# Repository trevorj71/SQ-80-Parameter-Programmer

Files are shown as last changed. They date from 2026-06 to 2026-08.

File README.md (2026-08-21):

# PG-80 Crosswave Parameter Programmer for Ensoniq SQ-80 and Ensoniq ESQ1

This repo contains open source hardware and software for the Ensoniq SQ-80 and ESQ-1 hybrid synthesizers, which I have named the "PG-80". It allows you to program up to 63 parameters in your synthesis engine using the 32 knobs on the front panel. It also supports hidden waves if your synth is equipped with an OS that supports them on the front panel. It also features a MIDI merge feature so you can run an input from your MIDI interface through the programmer to the synth, inserting the programmer in-line so it doesn't add unnecessarily to your workflow or MIDI rats nest.

I'm still tweaking the firmware to improve the knob layout and I have a new housing version in progress to accomodate a larger OLED display, but the current design is debugged and functional.

A BOM will be forthcoming when I have a few minutes to add it.

# Housing

My vision for this unit was always been a sidecar that can sit next to the synth on a stand designed for a 76 key workstation and looks like an extension of the synth to the extent possible.  Likely, you could design a smaller housing for desktop, as mine is not necessarily designed
to minimize its footprint or print time. 

The 3D models for the prototype are will be published here in both Fusion 360 and STL formats.

## Prototype Version (Adafruit 326 and PCB Mounted MIDI Connections)

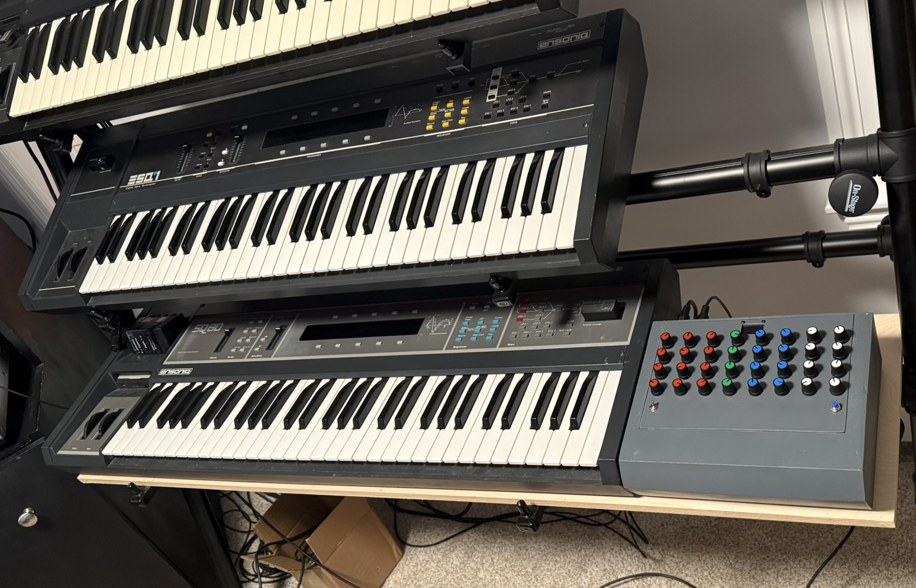
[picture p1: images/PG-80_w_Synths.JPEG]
PG-80 Programmer prototype with Ensoniq SQ-80 and Ensonig ESQ-1


For my first build, I used PCB mounted MIDI connectors and a PCB that was optimized for production and shipping cost. This left me with limited space between the knob array and the back panel of the unit for an OLED, so I used an Adafruit 326 0.91mm display.  This was fine for prototyping but in practice in the studio it is really hard to read.  Otherwise the knob layout feels good and the overall geometry of the print meets the vision. 

I did have some slippage in my printer late in this job (which took 5 days) so there is a bit of a bondo job on this, but it works for a prototype.

## In Progress Updgraded Version (Adafruit ... and Panel Mounted MIDI Connecitons)

Build two will switch to a 2.42 inch Adafruit 2719 and panel mounted MIDI connections. Design for that enclosure is under way.

# Glitch Mode (Hidden Waveform) and Shift Switch

This momentary pushbutton switch, SW2, has two functions. 

A quick tap of this swtich enables glitch mode. This allows knobs 1-3 (oscillator waveforms) to transmit all 255 available parameters to the synth. If you have an OS for your synth that supports hidden waveforms, you will be able to scroll through all 255 paramteters. This only works with the modified OS versions that support hidden waves.

Pressing and holding this switch while also turning a knob makes it function as a shift key, letting you change the MIDI channel on your device or modify up to 63 parameters in your synthesis workflow. Failing to turn a knob while the switch is depressed reverts the programmer to Glitch Mode / Standard Mode.

# Arch Mode (SQ-80 / ESQ-1) Toggle

A panel mounted toggle switch, SW1, facilitates switching between the 32 wave ESQ-1 table and the 75 wave SQ-80 table. In standard mode, this aligns the values sent by the oscillator waveform knobs within the desired range for your model synth. In Glitch Mode, this is more a matter of the mask used for the OLED on parameters 33-75, since all 255 parameters can be transmitted to the synth.

# Potentiometer Layout

Currently, the programmer has been laid out with 32 Potentiometers. You can access up to 63 parameters plus MIDI channel by pressing and holding the Hidden Waveforms button like a shift key.  

The knob layout as of version 1.5 is as follows:

### GLITCH BUTTON IN THE UP POSITION - NOT PRESSED

| Oscillator 1 | Oscillator 2 | Oscillator 3 | DCA-Filter | MOD 1 | MOD 2 | ENV 1-3 | ENV 2-4 
| :---: | :---: | :---: | :---: | :---: | :---: | :---: | :---: |
| WAVEFORM | WAVEFORM | WAVEFORM | DCA1 VOL | LFO1 WAVE | LFO2 FREQ | ENV1 ATK | ENV2 ATK 
| OSC1 FINE | OSC2 FINE | OSC3 FINE | DCA2 VOL | LFO1 FREQ | LFO3 WAVE | ENV1 DEC | ENV2 DEC 
| OSC1 COAR | OSC2 COAR | OSC3 COAR | DCA3 VOL | LFO1 DELY | LFO3 FREQ | ENV1 REL | ENV2 REL
| OSC1 OCT | OSC2 OCT | OSC3 OCT | ENV4 VOL | LFO2 WAVE | LFO3 DELY | ENV1 SUS | ENV2 SUS 

### GLITCH BUTTON HELD DOWN WHILE TURNING

| Oscillator 1 | Oscillator 2 | Oscillator 3 | DCA-Filter | MOD 1 | MOD 2 | ENV 1-3 | ENV 2-4 
| :---: | :---: | :---: | :---: | :---: | :---: | :---: | :---: |
| MOD1 SRC | MOD1 SRC | MOD1 SRC | FILT CUT | LFO1 L1 | LFO2 LS | ENV3 ATK | ENV4 ATK 
| MOD1 LEV | MOD1 LEV | MOD1 LEV | FILT RES | LFO1 L2 | LFO3 L1` | ENV3 DEC | ENV4 DEC 
| MOD2 SRC | MOD2 SRC | MOD2 SRC | FILT MOD3 | LFO2 DELY | LFO3 L2 | ENV3 REL | ENV4 REL
| MOD2 LEV | MOD2 LEV | MOD2 LEV | VOICE PAN | LFO2 L1 | MIDI CHAN | ENV3 SUS | ENV4 SUS

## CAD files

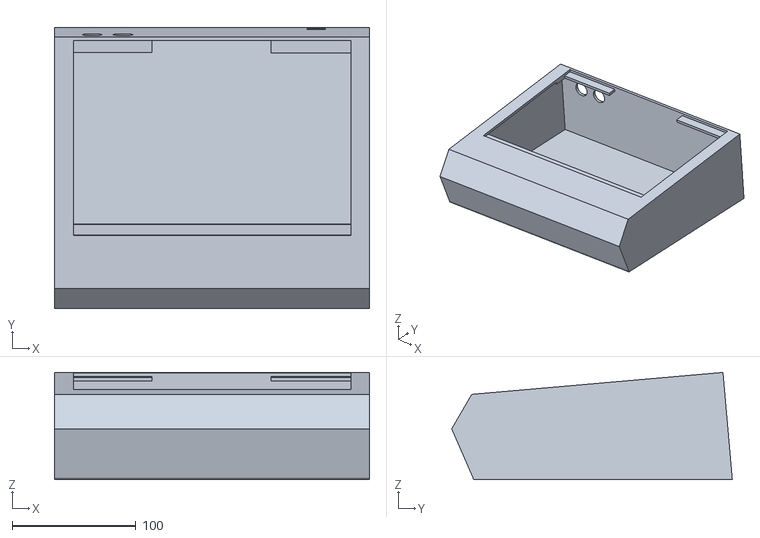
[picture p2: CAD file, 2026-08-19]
PG-80_Enclosure/V1-091 Display/Sliced Files/SQ80_Programmer_Housing_1_1.stl
255.0 x 227.2 x 86.7

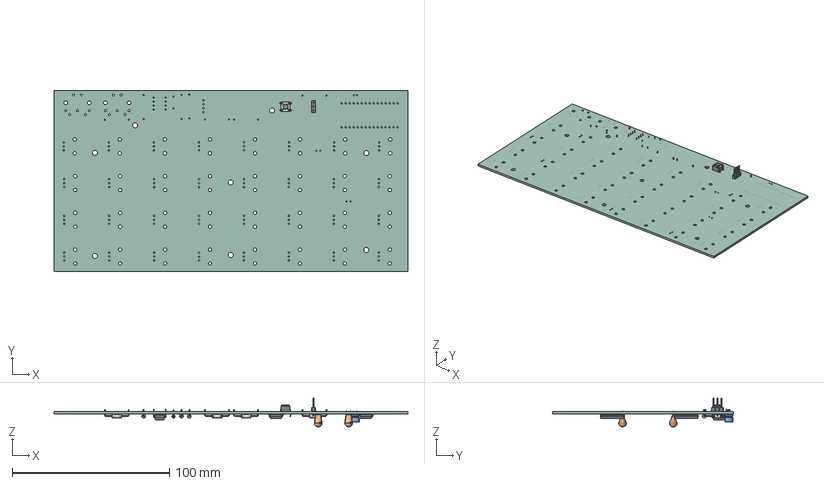
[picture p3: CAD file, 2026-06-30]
SQ80_Programmer_KiCad/PG-80.step
225.0 x 115.0 x 18.3 mm
SW_PUSH_6mm
PinHeader_1x03_P254mm_Vertical
DIP-8_W7.62mm
R_Axial_DIN0207_L63mm_D25mm_P1524mm_Horizontal x 7
SOIC-24W_7.5x15.4mm_P1.27mm x 2
CP_Radial_Tantal_D50mm_P250mm x 2
D_DO-35_SOD27_P7.62mm_Horizontal
CP_Radial_D50mm_P200mm
SQ80_Hardware_Programmer_PCB

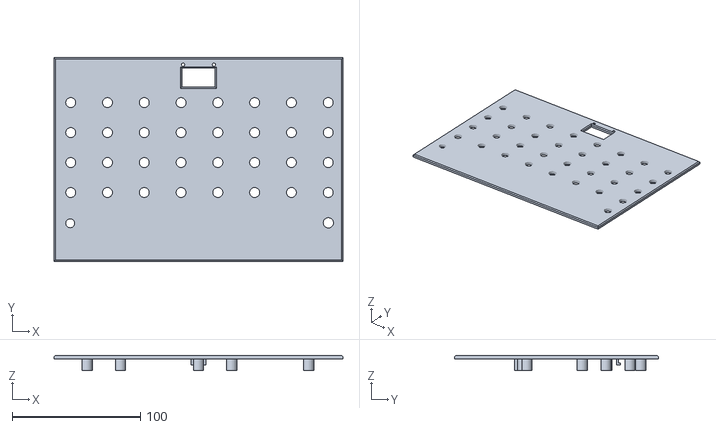
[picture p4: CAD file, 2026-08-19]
PG-80_Enclosure/V1-091 Display/Sliced Files/SQ-80_Lid4.stl
225.0 x 158.6 x 12.0

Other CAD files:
PG-80_Enclosure/V1-091 Display/Fusion360/SQ-80-2.f3d
PG-80_Enclosure/V1-091 Display/Fusion360/SQ-80_Lid2.f3d

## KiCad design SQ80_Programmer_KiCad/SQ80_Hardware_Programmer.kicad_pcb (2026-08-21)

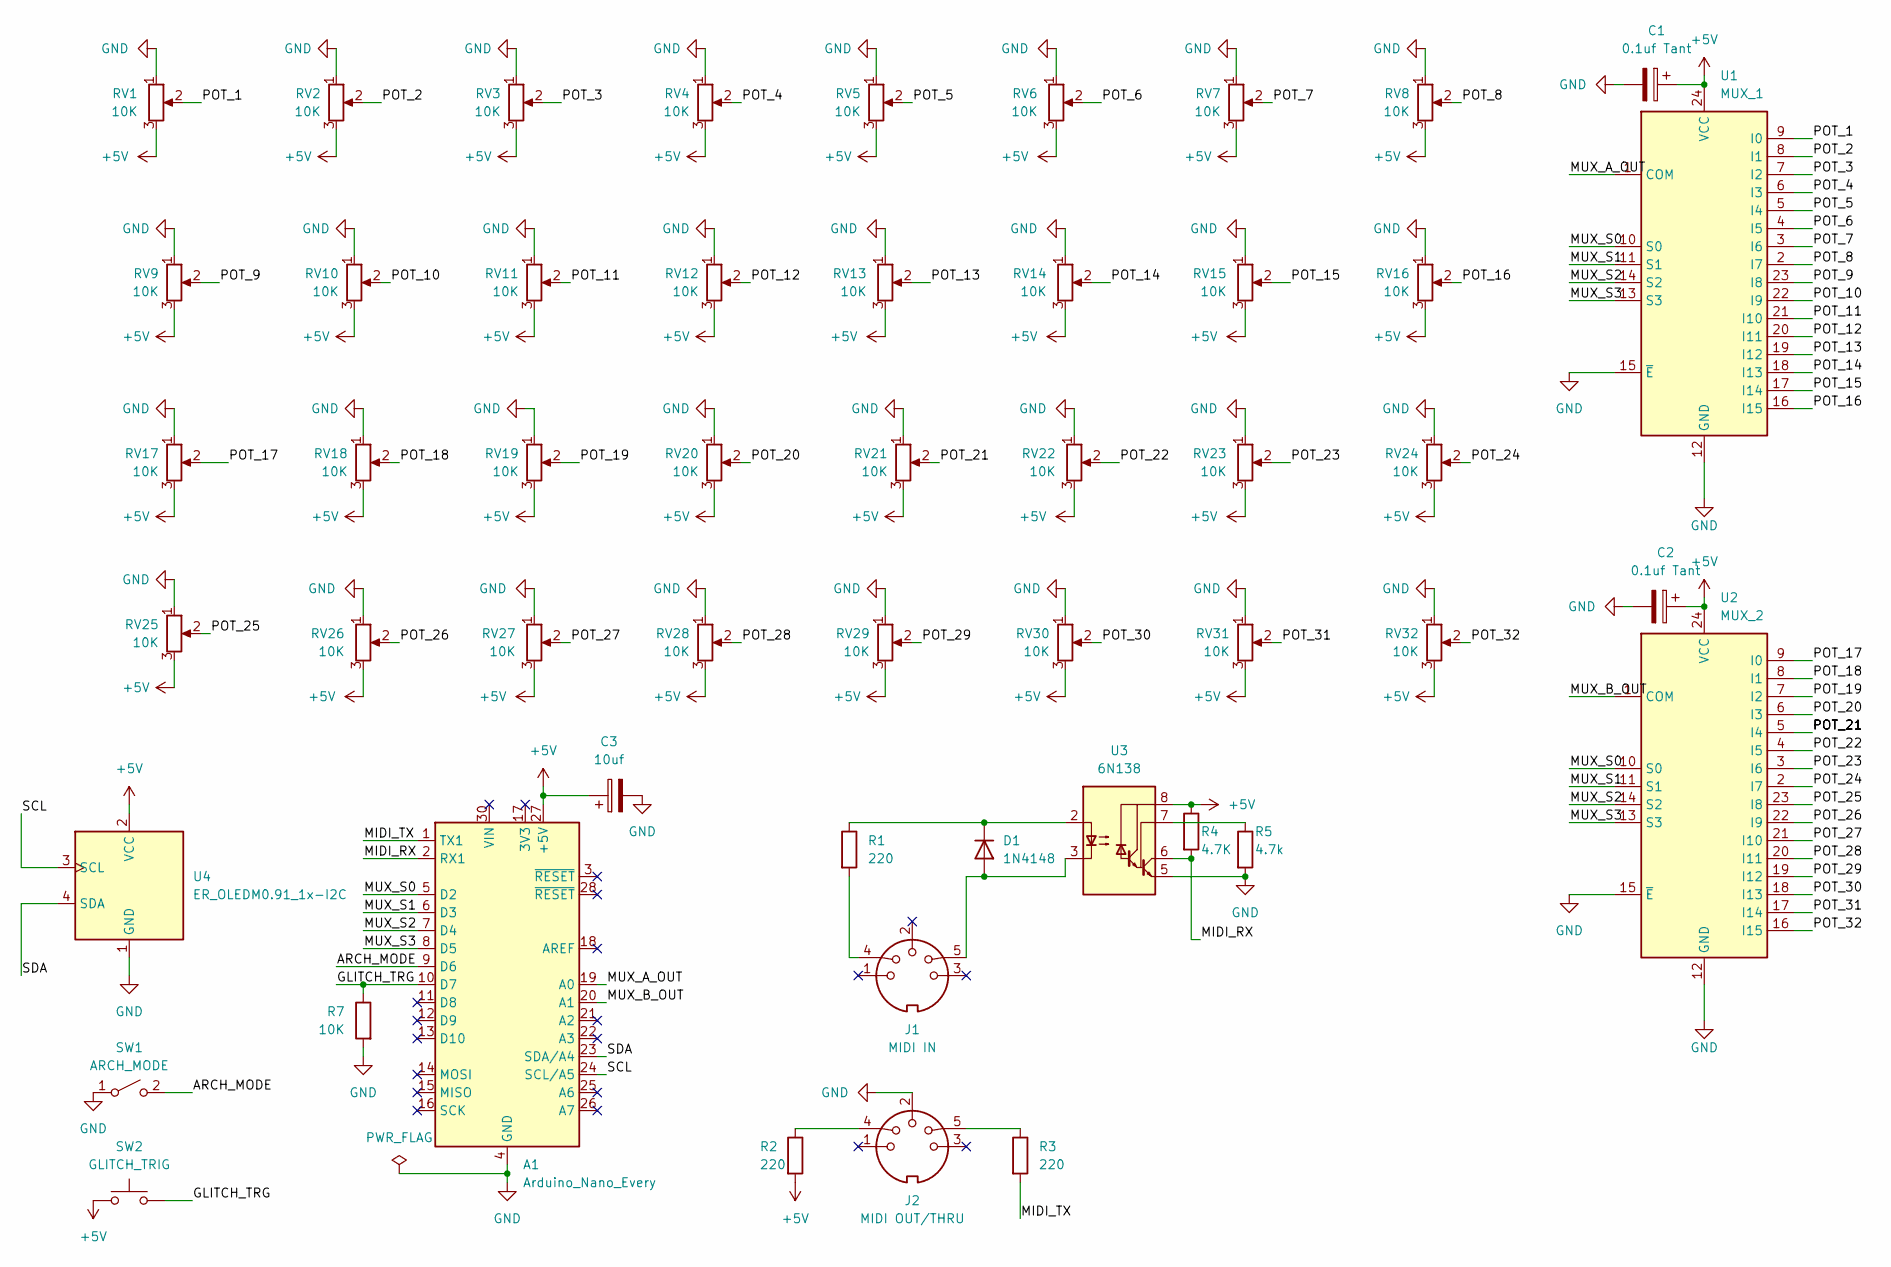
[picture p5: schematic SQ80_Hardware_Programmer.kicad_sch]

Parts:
A1: Arduino_Nano_Every; Arduino_Nano
C1, C2: 0.1uf Tant; CP_Radial_Tantal_D5.0mm_P2.50mm
C3: 10uf; CP_Radial_D5.0mm_P2.00mm
D1: 1N4148; D_DO-35_SOD27_P7.62mm_Horizontal
J1: MIDI IN; CONN5_SDS-50J_CUD
J2: MIDI OUT/THRU; CONN5_SDS-50J_CUD
R1, R2, R3: 220; R_Axial_DIN0207_L6.3mm_D2.5mm_P15.24mm_Horizontal
R4: 4.7K; R_Axial_DIN0207_L6.3mm_D2.5mm_P15.24mm_Horizontal
R5: 4.7k; R_Axial_DIN0207_L6.3mm_D2.5mm_P15.24mm_Horizontal
R7: 10K; R_Axial_DIN0207_L6.3mm_D2.5mm_P15.24mm_Horizontal
RV1, RV2, RV3, RV4, RV5, RV6, RV7, RV8, RV9, RV10, RV11, RV12, RV13, RV14, RV15, RV16, RV17, RV18, RV19, RV20, RV21, RV22, RV23, RV24, RV25, RV26, RV27, RV28, RV29, RV30, RV31, RV32: 10K; Potentiometer_Bourns_PTV09A-1_Single_Vertical
SW1: ARCH_MODE; PinHeader_1x03_P2.54mm_Vertical
SW2: GLITCH_TRIG; SW_PUSH_6mm
U1: MUX_1; SOIC-24W_7.5x15.4mm_P1.27mm
U2: MUX_2; SOIC-24W_7.5x15.4mm_P1.27mm
U3: 6N138; DIP-8_W7.62mm
U4: ER_OLEDM0.91_1x-I2C

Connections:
+5V: A1.27 (+5V), C1.1, C2.1, C3.1, R2.2, R4.1, RV1.3, RV2.3, RV3.3, RV4.3, RV5.3, RV6.3, RV7.3, RV8.3, RV9.3, RV10.3, RV11.3, RV12.3, RV13.3, RV14.3, RV15.3, RV16.3, RV17.3, RV18.3, RV19.3, RV20.3, RV21.3, RV22.3, RV23.3, RV24.3, RV25.3, RV26.3, RV27.3, RV28.3, RV29.3, RV30.3, RV31.3, RV32.3, SW2.1, U1.24 (VCC), U2.24 (VCC), U3.8 (VCC), U4.2 (VCC)
/ARCH_MODE: A1.9 (D6), SW1.2 (B)
/GLITCH_TRG: A1.10 (D7), R7.1, SW2.2
/MIDI_RX: A1.2 (RX1), R4.2, U3.6 (VO2)
/MIDI_TX: A1.1 (TX1), R3.2
/MUX_A_OUT: A1.19 (A0), U1.1 (COM)
/MUX_B_OUT: A1.20 (A1), U2.1 (COM)
/MUX_S0: A1.5 (D2), U1.10 (S0), U2.10 (S0)
/MUX_S1: A1.6 (D3), U1.11 (S1), U2.11 (S1)
/MUX_S2: A1.7 (D4), U1.14 (S2), U2.14 (S2)
/MUX_S3: A1.8 (D5), U1.13 (S3), U2.13 (S3)
/POT_1: RV1.2, U1.9 (I0)
/POT_2: RV2.2, U1.8 (I1)
/POT_3: RV3.2, U1.7 (I2)
/POT_4: RV4.2, U1.6 (I3)
/POT_5: RV5.2, U1.5 (I4)
/POT_6: RV6.2, U1.4 (I5)
/POT_7: RV7.2, U1.3 (I6)
/POT_8: RV8.2, U1.2 (I7)
/POT_9: RV9.2, U1.23 (I8)
/POT_10: RV10.2, U1.22 (I9)
/POT_11: RV11.2, U1.21 (I10)
/POT_12: RV12.2, U1.20 (I11)
/POT_13: RV13.2, U1.19 (I12)
/POT_14: RV14.2, U1.18 (I13)
/POT_15: RV15.2, U1.17 (I14)
/POT_16: RV16.2, U1.16 (I15)
/POT_17: RV17.2, U2.9 (I0)
/POT_18: RV18.2, U2.8 (I1)
/POT_19: RV19.2, U2.7 (I2)
/POT_20: RV20.2, U2.6 (I3)
/POT_21: RV21.2, U2.5 (I4)
/POT_22: RV22.2, U2.4 (I5)
/POT_23: RV23.2, U2.3 (I6)
/POT_24: RV24.2, U2.2 (I7)
/POT_25: RV25.2, U2.23 (I8)
/POT_26: RV26.2, U2.22 (I9)
/POT_27: RV27.2, U2.21 (I10)
/POT_28: RV28.2, U2.20 (I11)
/POT_29: RV29.2, U2.19 (I12)
/POT_30: RV30.2, U2.18 (I13)
/POT_31: RV31.2, U2.17 (I14)
/POT_32: RV32.2, U2.16 (I15)
/SCL: A1.24 (SCL/A5), U4.3 (SCL)
/SDA: A1.23 (SDA/A4), U4.4 (SDA)
GND: A1.4 (GND), A1.29 (GND), C1.2, C2.2, C3.2, J2.2, R5.2, R7.2, RV1.1, RV2.1, RV3.1, RV4.1, RV5.1, RV6.1, RV7.1, RV8.1, RV9.1, RV10.1, RV11.1, RV12.1, RV13.1, RV14.1, RV15.1, RV16.1, RV17.1, RV18.1, RV19.1, RV20.1, RV21.1, RV22.1, RV23.1, RV24.1, RV25.1, RV26.1, RV27.1, RV28.1, RV29.1, RV30.1, RV31.1, RV32.1, SW1.1 (A), U1.12 (GND), U1.15 (~E), U2.12 (GND), U2.15 (~E), U3.5 (GND), U4.1 (GND)
unnamed: D1.2 (A), J1.5, U3.3 (C2)
unnamed: D1.1 (K), R1.1, U3.2 (C1)
unnamed: J1.4, R1.2
unnamed: J2.4, R2.1
unnamed: J2.5, R3.1
unnamed: R5.1, U3.7 (VO1)

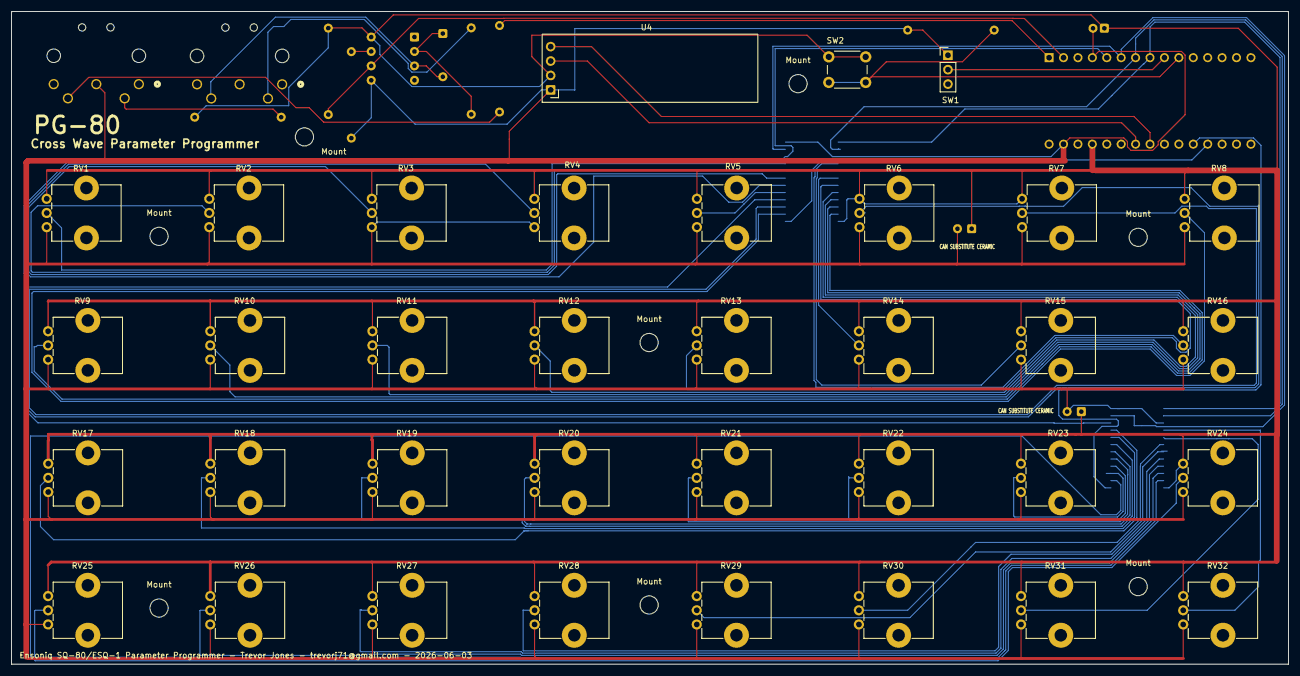
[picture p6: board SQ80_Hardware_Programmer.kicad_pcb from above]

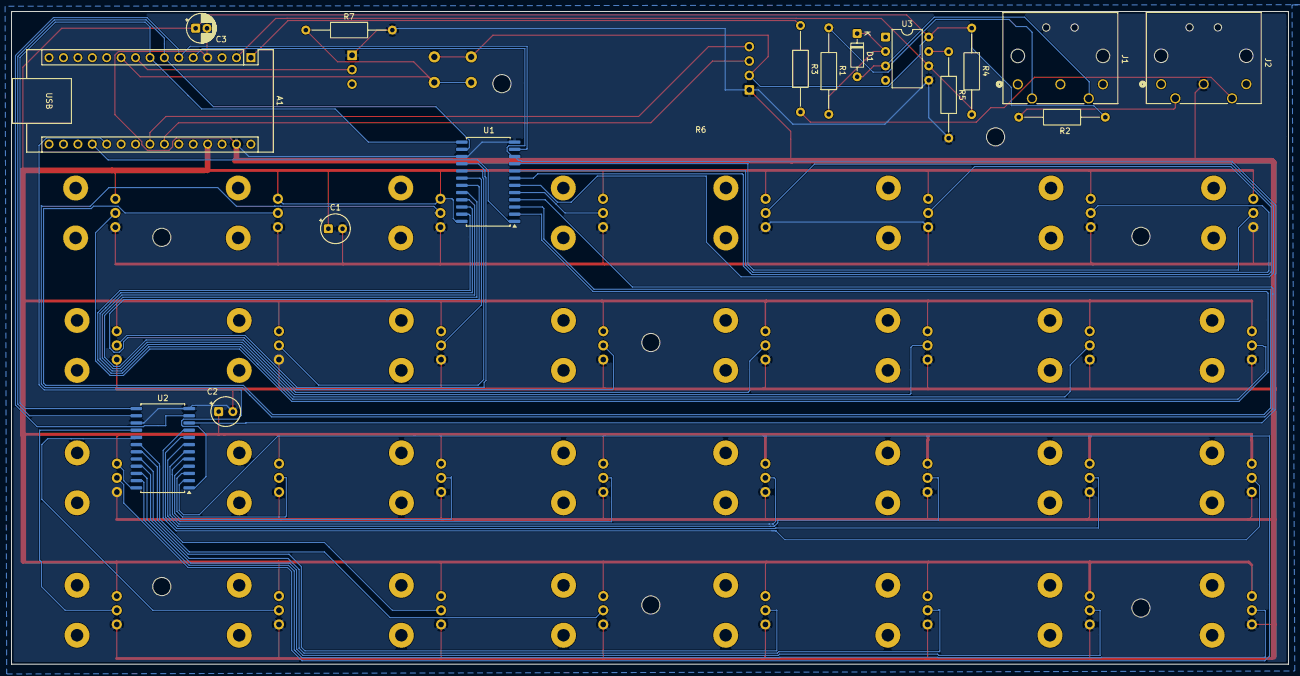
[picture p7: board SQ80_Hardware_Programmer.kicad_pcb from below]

Board: 2 copper layers, 225.0 x 115.0 mm, 59 parts (16 on the bottom side), 52 nets.

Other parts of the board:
Mount: MountingHole_3.2mm_M3
Mount#2, Mount#3, Mount#4, Mount#5, Mount#6, Mount#7, Mount#8: MountingHole_3.2mm_M3

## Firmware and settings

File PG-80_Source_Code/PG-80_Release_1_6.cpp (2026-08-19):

C++

#include <Wire.h>
#include <Adafruit_GFX.h>
#include <Adafruit_SSD1306.h>

// --- OLED DISPLAY CONFIGURATION ---
#define SCREEN_WIDTH 128
#define SCREEN_HEIGHT 64
Adafruit_SSD1306 display(SCREEN_WIDTH, SCREEN_HEIGHT, &Wire, -1);

// --- HARDWARE PIN DEFINITIONS ---
const int s0 = 2;
const int s1 = 3;
const int s2 = 4;
const int s3 = 5;

const int muxA = A0; // Channels 0-15 (Physical Pots 1-16)
const int muxB = A1; // Channels 0-15 (Physical Pots 17-32)

const int modelSwitchPin = 6;  
const int glitchButtonPin = 7; // Multi-gesture shift layer / glitch input button

// --- SYSTEM STATE VARIABLES ---
int lastPotState[32] = {0};
const int hysteresis = 8;         
bool isSQ80 = true;               
bool glitchMode = false;          // Starts up at "Hidden Waves: OFF"
bool lastGlitchButtonState = LOW;  // matches INPUT_PULLDOWN idle state

// --- GLOBAL MIDI SETTINGS ---
int midiChannel = 1;              

// --- ERA-ACCURATE FACTORY WAVEFORM LOOKUP TABLES ---
const char* const esq1Waves[32] = {
  "SAW", "SQUARE", "PULSE", "SINE", "NOISE", "REED", "ORGAN", "VOICE",
  "CHORD", "SYNTH", "BASS", "PIANO", "EL PNO", "VOX 1", "VOX 2", "BREATH",
  "DRUM 1", "DRUM 2", "DRUM 3", "KICK", "SNARE", "TOM", "HI-HAT", "PERC 1",
  "SYN 2", "SYN 3", "MELLON", "OCTAVE", "FIFTH", "PIRATE", "GHOST", "HEAVEN"
};
const char* const sq80ExtraWaves[43] = {
  "GLINT 1", "GLINT 2", "GLINT 3", "GLINT 4", "GLINT 5", "GLINT 6", "GRIT 1", "GRIT 2", 
  "GRIT 3", "WRONG", "SNARE", "KICK", "TOM", "HI-HAT", "RIM", "BREATH", 
  "VOICE 2", "STEAM", "METAL", "CHIME", "BOWED", "STRUCK", "PLUCK", "PLINK", 
  "CHIFF", "THUMP", "CLICK", "LOG", "XLYO", "MALLET", "ORGAN 2", "NEIGH", 
  "ROBOT", "SQUAWK", "ALARM", "REVERSE", "LOOP 1", "LOOP 2", "LOOP 3", "LOOP 4", 
  "LOOP 5", "LOOP 6", "MAC"
};
const char* const lfoWaves[5] = {
  "TRIANGLE", "SAWTOOTH", "SQUARE", "RANDOM", "NOISE"
};

// --- PARAMETER LOOKUP TABLE: COLUMN-FIRST LAYOUT ---
// Physical layout: 8 columns x 4 rows, read left-to-right top-to-bottom.
// Each column groups a parameter family so pots in the same column are
// visually consistent with the SQ-80's front panel button groupings.
const int sq80Parameters[32] = {
  // Row 1 (Pots 1-8):   one pot per column, top knob of each group
  3,  7,  11, 12, 17, 24, 43, 50,
  // Pots 1-8: OSC1 Wave | OSC2 Wave | OSC3 Wave | DCA1 Vol | LFO1 Wave | LFO2 Freq | ENV1 Atk | ENV2 Atk

  // Row 2 (Pots 9-16):  second knob of each group
  1,  5,  9,  13, 15, 35, 44, 51,
  // Pots 9-16: OSC1 Semi | OSC2 Semi | OSC3 Semi | DCA2 Vol | LFO1 Freq | LFO3 Wave | ENV1 Dec | ENV2 Dec

  // Row 3 (Pots 17-24): third knob of each group
  2,  6,  10, 14, 16, 33, 46, 53,
  // Pots 17-24: OSC1 Fine | OSC2 Fine | OSC3 Fine | DCA3 Vol | LFO1 Dly | LFO3 Freq | ENV1 Rel | ENV2 Rel

  // Row 4 (Pots 25-32): fourth/bottom knob of each group
  0,  4,  8,  23, 26, 32, 48, 55
  // Pots 25-32: OSC1 Oct | OSC2 Oct | OSC3 Oct | Patch Vol | LFO2 Wave | LFO3 Dly | ENV1 Sus | ENV2 Sus
};

// Track whether Pot 32 was adjusted while shift was held down
bool pot32AdjustedDuringShift = false;

// Track what's currently on screen so other events (e.g. model switch) can redraw it
int lastDisplayedParamID = -1;
int lastDisplayedValue = 0;

// Reads a pot's raw ADC value with rotation direction inverted, so that
// clockwise rotation increases the value (matching typical studio gear),
// instead of the hardware's native counter-clockwise-to-increase wiring.
int readPot(int analogPin) {
  return 1023 - analogRead(analogPin);
}

// --- ENSONIQ HARDWARE MIDI PARAMETER TRANSLATOR ---
// Returns -1 for parameters whose NRPN address is not yet confirmed from the
// manual. The send path skips transmission for -1 to prevent corrupting the
// patch with a garbage address. Verify and fill these in after bench testing.
int translateToEnsoniqParam(int internalID) {
  switch(internalID) {
    // OSC 1 (NRPN block 64-71)
    case 0:  return 64; // OSC 1 OCTAVE
    case 1:  return 65; // OSC 1 SEMI
    case 2:  return 66; // OSC 1 FINE
    case 3:  return 67; // OSC 1 WAVE
    case 70: return 68; // OSC 1 MOD 1 SOURCE
    case 71: return 69; // OSC 1 MOD 1 LEVEL
    case 72: return 70; // OSC 1 MOD 2 SOURCE
    case 73: return 71; // OSC 1 MOD 2 LEVEL

    // OSC 2 (NRPN block 72-79)
    case 4:  return 72; // OSC 2 OCTAVE
    case 5:  return 73; // OSC 2 SEMI
    case 6:  return 74; // OSC 2 FINE
    case 7:  return 75; // OSC 2 WAVE
    case 74: return 76; // OSC 2 MOD 1 SOURCE
    case 75: return 77; // OSC 2 MOD 1 LEVEL
    case 76: return 78; // OSC 2 MOD 2 SOURCE
    case 77: return 79; // OSC 2 MOD 2 LEVEL

    // OSC 3 (NRPN block 80-87)
    case 8:  return 80; // OSC 3 OCTAVE
    case 9:  return 81; // OSC 3 SEMI
    case 10: return 82; // OSC 3 FINE
    case 11: return 83; // OSC 3 WAVE
    case 78: return 84; // OSC 3 MOD 1 SOURCE
    case 79: return 85; // OSC 3 MOD 1 LEVEL
    case 80: return 86; // OSC 3 MOD 2 SOURCE
    case 81: return 87; // OSC 3 MOD 2 LEVEL

    // DCA / VCF
    case 12: return 88; // DCA 1 LEVEL
    case 13: return 94; // DCA 2 LEVEL
    case 14: return 100;// DCA 3 LEVEL
    case 18: return 110;// FILTER CUTOFF
    case 19: return 111;// FILTER RESONANCE
    case 82: return 112;// FILTER MODULATION AMOUNT 3

    // LFO 1 (NRPN block 40-47)
    case 15: return 40; // LFO 1 FREQ
    case 16: return 45; // LFO 1 DELAY
    case 17: return 43; // LFO 1 WAVE
    case 83: return 44; // LFO 1 L1
    case 84: return 46; // LFO 1 L2

    // LFO 2 (NRPN block 48-55)
    case 24: return 48; // LFO 2 FREQ
    case 25: return 53; // LFO 2 DELAY
    case 26: return 51; // LFO 2 WAVE
    case 85: return 52; // LFO 2 L1
    case 86: return 54; // LFO 2 L2

    // LFO 3 (NRPN block 56-63)
    case 33: return 56; // LFO 3 FREQ
    case 32: return 61; // LFO 3 DELAY
    case 35: return 59; // LFO 3 WAVE
    case 87: return 60; // LFO 3 L1
    case 88: return 62; // LFO 3 L2

    // Misc
    case 23: return 30; // PATCH VOLUME (DCA 4 VOL)
    case 42: return 107;// PAN POSITION

    // ENV 1 (NRPN block 0-9)
    case 43: return 5;  // ENV 1 T1 (Attack)
    case 44: return 6;  // ENV 1 T2 (Decay)
    case 46: return 8;  // ENV 1 T4 (Release)
    case 48: return 2;  // ENV 1 L3 (Sustain)

    // ENV 2 (NRPN block 10-19)
    case 50: return 15; // ENV 2 T1 (Attack)
    case 51: return 16; // ENV 2 T2 (Decay)
    case 53: return 18; // ENV 2 T4 (Release)
    case 55: return 12; // ENV 2 L3 (Sustain)

    // ENV 3 (NRPN block 20-29)
    case 56: return 25; // ENV 3 T1 (Attack)
    case 57: return 26; // ENV 3 T2 (Decay)
    case 59: return 28; // ENV 3 T4 (Release)
    case 62: return 22; // ENV 3 L3 (Sustain)

    // ENV 4 (NRPN block 30-39)
    case 64: return 35; // ENV 4 T1 (Attack)
    case 65: return 36; // ENV 4 T2 (Decay)
    case 67: return 38; // ENV 4 T4 (Release)
    case 68: return 32; // ENV 4 L3 (Sustain)

    default: return internalID;
  }
}

// --- MIDI MERGE HELPER ---
// Drains all pending bytes from Serial1 RX (MIDI IN) to Serial1 TX (MIDI OUT).
// Called in multiple places — top of loop(), inside the scan loop, and before
// each NRPN send — so the 64-byte RX hardware buffer never has time to overflow
// even during slow I2C OLED updates or back-to-back parameter changes.
// All channels are passed through unconditionally; this is a transparent merge.
inline void flushMIDIMerge() {
  while (Serial1.available() > 0) {
    Serial1.write((uint8_t)Serial1.read());
  }
}

void setup() {
  delay(200); // Give physical OLED power rail time to stabilize
  Wire.begin(); // Wake up I2C controller

  Serial1.begin(31250); // Hardware MIDI protocol

  pinMode(s0, OUTPUT);
  pinMode(s1, OUTPUT);
  pinMode(s2, OUTPUT);
  pinMode(s3, OUTPUT);

  pinMode(modelSwitchPin, INPUT_PULLUP);
  pinMode(glitchButtonPin, INPUT_PULLDOWN);

  if(!display.begin(SSD1306_SWITCHCAPVCC, 0x3D)) { 
    pinMode(LED_BUILTIN, OUTPUT);
    while(true) {
      digitalWrite(LED_BUILTIN, HIGH); delay(100);
      digitalWrite(LED_BUILTIN, LOW);  delay(100);
    }
  }
  
  // Set initial model state cleanly based on hardware layout
  isSQ80 = (digitalRead(modelSwitchPin) == LOW);
  display.clearDisplay();
  display.setTextColor(WHITE);
  display.setTextSize(2);
  display.setCursor(0, 0);
  display.println("PG-80");
  display.drawLine(0, 18, 128, 18, WHITE);
  
  display.setTextSize(1);
  display.setCursor(0, 24);
  display.println("CROSS WAVE PROGRAMMER");
  display.setCursor(0, 36);
  display.println("Hardware Map Confirmed");
  display.setCursor(0, 48);
  display.println("Firmware Profile v2.2");

  display.display();
  delay(2000);

  // --- SEED INITIAL POT STATE TO PREVENT POWER-ON PARAMETER DUMP ---
  // Read every pot's current physical position once, silently, so the
  // first loop() scan has a true baseline and doesn't interpret "knob
  // sits away from zero" as "knob just moved."
  for (int channel = 0; channel < 16; channel++) {
    digitalWrite(s0, (channel >> 0) & 1);
    digitalWrite(s1, (channel >> 1) & 1);
    digitalWrite(s2, (channel >> 2) & 1);
    digitalWrite(s3, (channel >> 3) & 1);
    delayMicroseconds(30);

    lastPotState[channel]      = readPot(muxA);
    lastPotState[channel + 16] = readPot(muxB);
  }

  // Draw the idle/ready screen (also draws the engine badge for the first time)
  updateOLED(-1, 0);
}

void loop() {
  // 1. DYNAMIC SWITCH EVALUATION INTERFACE
  bool currentModel = (digitalRead(modelSwitchPin) == LOW);
  if (currentModel != isSQ80) {
    isSQ80 = currentModel;
    // Redraw whatever's currently on screen so the engine badge updates
    // in the same fixed slot every time, with no separate overlay logic.
    updateOLED(lastDisplayedParamID, lastDisplayedValue);
  }

  // MIDI merge: drain RX → TX at the top of every loop() iteration.
  // Also called inside the scan loop and before each NRPN send.
  flushMIDIMerge();

  // Read current shifting key array state
  bool currentGlitchButtonState = digitalRead(glitchButtonPin);
  bool isShifted = (currentGlitchButtonState == HIGH);

  // 2. SYNCHRONOUS MULTIPLEXER ROW SCANNING ENGINE
  for (int channel = 0; channel < 16; channel++) {
    // Service the MIDI merge on every channel iteration so incoming bytes
    // are forwarded even during pot scans and OLED updates.
    flushMIDIMerge();

    // Explicitly shift bits right so they always evaluate to a strict 0 or 1
    digitalWrite(s0, (channel >> 0) & 1);
    digitalWrite(s1, (channel >> 1) & 1);
    digitalWrite(s2, (channel >> 2) & 1);
    digitalWrite(s3, (channel >> 3) & 1);
    delayMicroseconds(30);

    int valA = readPot(muxA);
    int valB = readPot(muxB);
    
    checkAndSendMIDI(channel, valA, isShifted);
    checkAndSendMIDI(channel + 16, valB, isShifted);
  }

  // 3. SEPARATED MULTI-GESTURE TACTILE BUTTON PARSER
  // MIDI channel is now on Pot 30 shifted (potID 29, Mux B channel 13).
  // Set MUX select lines to channel 13 and sample Mux B directly here,
  // outside the main scan loop, to detect whether that pot moved.
  if (isShifted) {
    digitalWrite(s0, (13 >> 0) & 1);
    digitalWrite(s1, (13 >> 1) & 1);
    digitalWrite(s2, (13 >> 2) & 1);
    digitalWrite(s3, (13 >> 3) & 1);
    delayMicroseconds(30);
    int currentPot30Val = readPot(muxB); // Pot 30: LFO 3 Delay, shifted = MIDI Channel
    if (abs(currentPot30Val - lastPotState[29]) > hysteresis) {
      pot32AdjustedDuringShift = true;
    }
  }

  // Check for physical button release
  if (currentGlitchButtonState == LOW && lastGlitchButtonState == HIGH) {
    if (pot32AdjustedDuringShift) {
      pot32AdjustedDuringShift = false; // Reset modifier flag cleanly
      
      display.clearDisplay();
      display.setCursor(0, 20);
      display.setTextSize(1);
      display.print("CHANNEL LOCKED IN");
      display.display();
      delay(600);
    } 
    else {
      glitchMode = !glitchMode;
      display.clearDisplay();
      display.setCursor(0, 20);
      display.setTextSize(1); 
      if (glitchMode) display.print("HIDDEN WAVES: ON");
      else display.print("HIDDEN WAVES: OFF");
      display.display();
      delay(500);
    }
  }
  lastGlitchButtonState = currentGlitchButtonState;
}

void checkAndSendMIDI(int potID, int currentRawValue, bool shiftActive) {
  if (abs(currentRawValue - lastPotState[potID]) > hysteresis) {
    
    lastPotState[potID] = currentRawValue;

    // INTERCEPT 1: Absolute Global System MIDI Channel Assignment (Pot 30 Shift Layer)
    if (potID == 29 && shiftActive) {
      midiChannel = map(currentRawValue, 0, 1023, 1, 16);
      display.clearDisplay();
      display.setTextColor(WHITE);
      display.setTextSize(1);
      display.setCursor(0, 5);
      display.print("GLOBAL SYSTEM CFG");
      display.drawLine(0, 16, 128, 16, WHITE);
      display.setCursor(0, 26);
      display.print("SET OUT CHANNEL:");
      display.setTextSize(2);
      display.setCursor(0, 42);
      display.print("CH: ");
      display.print(midiChannel);
      display.display();
      return; 
    }
    
    int paramID = sq80Parameters[potID];

    // INTERCEPT 2: Multi-Layer Macro Shift Transformation Redirections
    // potID values are 0-based (potID = pot number - 1).
    // MIDI CHANNEL is now on Pot 30 (potID 29) shifted — caught by INTERCEPT 1 above.
    // Pot 32 (potID 31) shifted now carries ENV 4 SUSTAIN.
    if (shiftActive) {
      switch(potID) {
        // --- OSC 1 MOD MATRIX (Col 1 shifted) ---
        case 0:  paramID = 70; break; // Pot 1:  OSC 1 Wave     -> OSC 1 Mod 1 Source
        case 8:  paramID = 71; break; // Pot 9:  OSC 1 Semi     -> OSC 1 Mod 1 Level
        case 16: paramID = 72; break; // Pot 17: OSC 1 Fine     -> OSC 1 Mod 2 Source
        case 24: paramID = 73; break; // Pot 25: OSC 1 Oct      -> OSC 1 Mod 2 Level
        // --- OSC 2 MOD MATRIX (Col 2 shifted) ---
        case 1:  paramID = 74; break; // Pot 2:  OSC 2 Wave     -> OSC 2 Mod 1 Source
        case 9:  paramID = 75; break; // Pot 10: OSC 2 Semi     -> OSC 2 Mod 1 Level
        case 17: paramID = 76; break; // Pot 18: OSC 2 Fine     -> OSC 2 Mod 2 Source
        case 25: paramID = 77; break; // Pot 26: OSC 2 Oct      -> OSC 2 Mod 2 Level
        // --- OSC 3 MOD MATRIX (Col 3 shifted) ---
        case 2:  paramID = 78; break; // Pot 3:  OSC 3 Wave     -> OSC 3 Mod 1 Source
        case 10: paramID = 79; break; // Pot 11: OSC 3 Semi     -> OSC 3 Mod 1 Level
        case 18: paramID = 80; break; // Pot 19: OSC 3 Fine     -> OSC 3 Mod 2 Source
        case 26: paramID = 81; break; // Pot 27: OSC 3 Oct      -> OSC 3 Mod 2 Level
        // --- DCA / FILTER / MISC (Col 4 shifted) ---
        case 3:  paramID = 18; break; // Pot 4:  DCA 1 Vol      -> Filter Cutoff
        case 11: paramID = 19; break; // Pot 12: DCA 2 Vol      -> Filter Resonance
        case 19: paramID = 82; break; // Pot 20: DCA 3 Vol      -> Filter Mod Amount 3
        case 27: paramID = 42; break; // Pot 28: Patch Vol      -> Voice Pan
        // --- LFO LEVELS (Cols 5-6 shifted) ---
        case 4:  paramID = 83; break; // Pot 5:  LFO 1 Wave     -> LFO 1 L1
        case 12: paramID = 84; break; // Pot 13: LFO 1 Freq     -> LFO 1 L2
        case 20: paramID = 25; break; // Pot 21: LFO 1 Delay    -> LFO 2 Delay
        case 28: paramID = 85; break; // Pot 29: LFO 2 Wave     -> LFO 2 L1
        case 5:  paramID = 86; break; // Pot 6:  LFO 2 Freq     -> LFO 2 L2
        case 13: paramID = 87; break; // Pot 14: LFO 3 Wave     -> LFO 3 L1
        case 21: paramID = 88; break; // Pot 22: LFO 3 Freq     -> LFO 3 L2
        // potID 29 (Pot 30): LFO 3 Delay -> MIDI Channel; caught by INTERCEPT 1 above.
        // --- ENV 1 / ENV 3 (Col 7 shifted) ---
        case 6:  paramID = 56; break; // Pot 7:  ENV 1 Attack   -> ENV 3 Attack
        case 14: paramID = 57; break; // Pot 15: ENV 1 Decay    -> ENV 3 Decay
        case 22: paramID = 59; break; // Pot 23: ENV 1 Release  -> ENV 3 Release
        case 30: paramID = 62; break; // Pot 31: ENV 1 Sustain  -> ENV 3 Sustain
        // --- ENV 2 / ENV 4 (Col 8 shifted) ---
        case 7:  paramID = 64; break; // Pot 8:  ENV 2 Attack   -> ENV 4 Attack
        case 15: paramID = 65; break; // Pot 16: ENV 2 Decay    -> ENV 4 Decay
        case 23: paramID = 67; break; // Pot 24: ENV 2 Release  -> ENV 4 Release
        case 31: paramID = 68; break; // Pot 32: ENV 2 Sustain  -> ENV 4 Sustain
      }
    }
    
    int ensoniqValue;

    // --- DYNAMIC ADAPTIVE PARAMETER MAPPING ENGINE ---
    if (paramID == 18) {
      ensoniqValue = map(currentRawValue, 0, 1023, 0, 127);
    } else if (paramID == 3 || paramID == 7 || paramID == 11) {
      if (glitchMode) {
        // Glitch mode extends beyond the standard wavetable.
        // Hard ceiling is 127 — MIDI data bytes are 7-bit only.
        // Values >= 128 set the high bit and are interpreted as status bytes,
        // corrupting the NRPN message. Hidden waves live in the 75-127 range
        // (SQ-80) or 32-127 range (ESQ-1) — both fully reachable at 0-127.
        ensoniqValue = map(currentRawValue, 0, 1023, 0, 127);
      } else {
        if (isSQ80) ensoniqValue = map(currentRawValue, 0, 1023, 0, 74);
        else ensoniqValue = map(currentRawValue, 0, 1023, 0, 31);
      }
    } else if (paramID == 17 || paramID == 26 || paramID == 35) {
      if (isSQ80) ensoniqValue = map(currentRawValue, 0, 1023, 0, 4);
      else ensoniqValue = map(currentRawValue, 0, 1023, 0, 3);
    } else if (paramID == 19 || paramID == 2 || paramID == 6 || paramID == 10) {
      ensoniqValue = map(currentRawValue, 0, 1023, 0, 31);
    } else if (paramID == 42) {
      ensoniqValue = map(currentRawValue, 0, 1023, 0, 15);
    } else {
      ensoniqValue = map(currentRawValue, 0, 1023, 0, 63);
    }

    // Drain the merge buffer immediately before sending our own NRPN bytes,
    // so incoming MIDI is forwarded before we occupy the TX buffer.
    flushMIDIMerge();

    // Convert our internal layout code ID to Ensoniq's true NRPN parameter target index.
    // translateToEnsoniqParam() returns -1 for parameters whose NRPN address is not yet
    // confirmed. Skip transmission entirely in that case to avoid corrupting the patch.
    int realMIDIParameter = translateToEnsoniqParam(paramID);
    if (realMIDIParameter >= 0) {
      sendEnsoniqNRPN(realMIDIParameter, ensoniqValue);
    }
    updateOLED(paramID, ensoniqValue);
  }
}

void sendEnsoniqNRPN(int parameter, int value) {
  uint8_t statusByte = 0xB0 + (midiChannel - 1);
  Serial1.write(statusByte);
  Serial1.write(99);
  Serial1.write(0);
  
  Serial1.write(statusByte);
  Serial1.write(98);
  Serial1.write(parameter); // Safely translated Ensoniq target ID
  
  Serial1.write(statusByte);
  Serial1.write(6);
  Serial1.write(value);
}
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

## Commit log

2026-06-30 Create KiCad_Project
2026-06-30 Initial Upload of KiCad files and Code
    [PG-80.step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]
2026-07-21 Firmware and PCB Edits
    PCB updated to remove redundant resistors. Firmware updated to 63 pameters plus midi channel and columnar POT layout.
2026-07-23 Version 1.5 Updates to Col 4
    Updates to knob positions in column 4 (DCA and Filter) for better programming flow.
2026-08-19 Enclosure and README Updates
    Adding the prototype/V1 enclosure and some updates to the README.
    [SQ-80-2.f3d, SQ-80_Lid2.f3d, SQ-80_Lid4.stl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]
2026-08-20 PCB and Readme Updates
    Added functional descriptions for SW1 and SW2 in README. Update PCB to add R5 to MIDI input section.
    [SQ80_Hardware_Programmer.kicad_pcb, SQ80_Hardware_Programmer.kicad_sch]
2026-08-20 README Edits
    Edits to Intro, Housing, and Glitch Sections
2026-08-21 README Edits
    [SQ80_Hardware_Programmer.kicad_pcb]
2026-08-21 REAMDMe Edits
    Enclosure and more in intro.
